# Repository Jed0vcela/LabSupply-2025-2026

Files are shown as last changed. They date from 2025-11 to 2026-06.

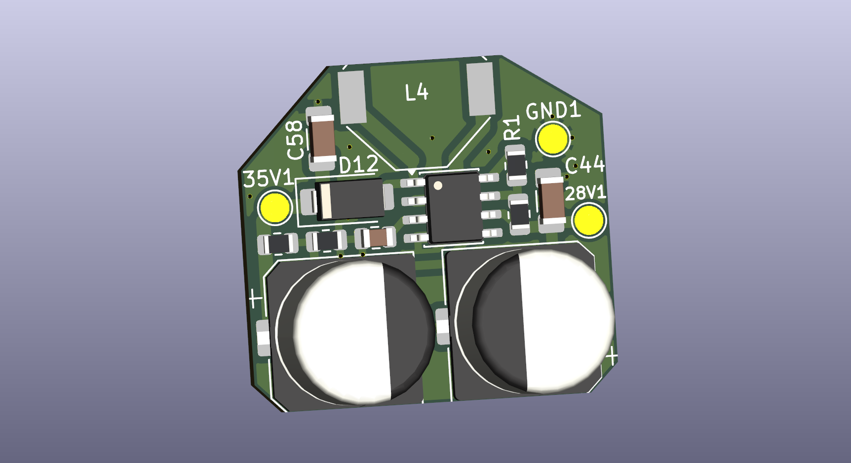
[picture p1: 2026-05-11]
KiCad soubory/OPamp_boost1/OPamp_boost1.png

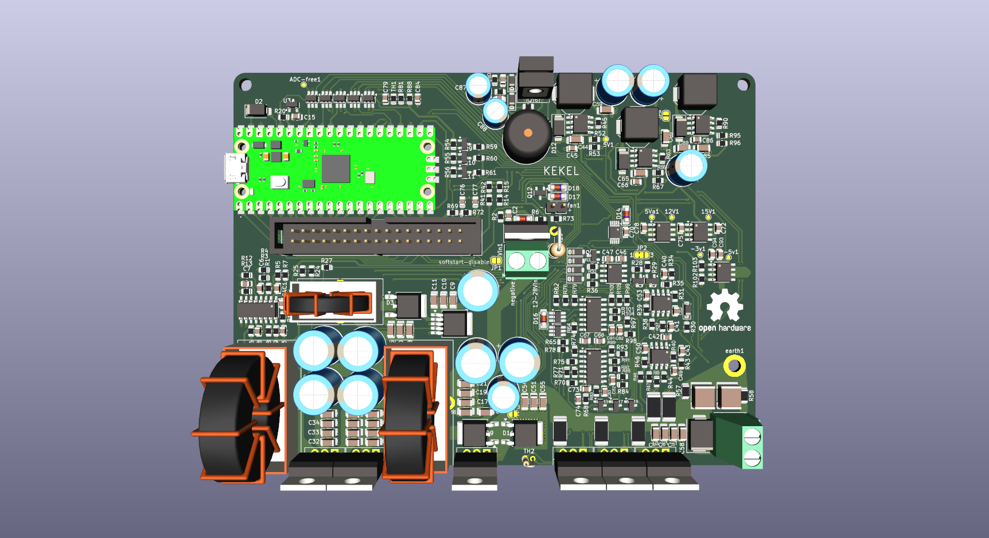
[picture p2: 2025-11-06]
KiCad soubory/Power board/LabSupply 2025-2026.png

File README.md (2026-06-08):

# Laboratorní napájecí zdroj + elektronická zátěž

Kombinovaný zdroj a elektronická zátěž na společných výstupních svorkách — vhodný pro nabíjení i vybíjení baterií.

## Napájení

- **USB-C** nebo **XT60** konektor (12–30 V, např. z akumulátorů)
- Výstupní napětí může být vyšší i nižší než vstupní (výstup **není galvanicky oddělen** od vstupu)

## Parametry

| Parametr | Hodnota |
|---|---|
| Výstupní napětí | 0 – 35 V |
| Výstupní proud (zdroj) | 0 – 4,5 A |
| Proudová zátěž | 0 – 3,8 A (max. 20 W) |

## Funkce

- **Zdroj** — nastavitelné napětí a proud (Vset, Iset)
- **Elektronická zátěž** — nastavitelný proudový sink (Isink), souběžně se zdrojem
- **Měřič kontinuity** — nastavitelný práh napětí, akustická signalizace
- **Ochrana výkonu** — konfigurovatelné limity Pout a Psink, ochrana při poklesu Vin
- **Kalibrace** — nastavení gain/offset pro každý měřený kanál, uložení do interní flash
- **Ukládání nastavení** — hodnoty Vset, Iset a Isink se ukládají do flash
- **IR dálkové ovládání** — NEC protokol, zatím není implementováno
- **LCD displej** — barevný 160×128 px, tři zobrazovací režimy

## Hardware

Raspberry Pi Pico (RP2040) · MCP4728 DAC · MCP23S17 · ST7735S LCD · rotační enkodér · NTC teplotní senzory · ventilátor · bzučák

## Dokumentace

Podrobný uživatelský manuál: [`manual_napajeci_zdroj.md`](manual_napajeci_zdroj.md)





LabSupply 2025-2026

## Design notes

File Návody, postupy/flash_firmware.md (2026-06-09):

# Nahrávání firmwaru

## Požadavky

- Micro USB kabel
- PC (Windows, macOS nebo Linux)
- Soubor `firmware.uf2` — stáhnout z [GitHub – Zkompilované programy](https://github.com/Jed0vcela/LabSupply-2025-2026/tree/main/Kompilovan%C3%A9%20programy)

---

## Postup nahrání firmwaru

**1.** Odpojte zdroj od napájení.

**2.** Odstraňte přední kryt zdroje.

**3.** Stiskněte a **držte** tlačítko **BOOTSEL** na Raspberry Pi Pico.

<!-- přidám obrázek -->
bootsel

**4.** Při stále stisknutém tlačítku připojte micro USB kabel do PC.  
Zdroj se zobrazí jako USB flash disk (mass storage) s názvem `RPI-RP2`.

**5.** Tlačítko BOOTSEL uvolněte.

**6.** Stáhněte nejnovější `firmware.uf2` z [GitHub – Zkompilované programy](https://github.com/Jed0vcela/LabSupply-2025-2026/tree/main/Kompilovan%C3%A9%20programy).

**7.** Přetáhněte soubor `firmware.uf2` na disk `RPI-RP2`.

<!-- přidám obrázek -->
nahrání fw

**8.** Zařízení se automaticky odpojí od PC, resetuje a spustí nový firmware.

---

## Vymazání paměti flash (reset kalibrace) (není normálně potřeba)

Hodnoty uložené v paměti FLASH (kalibrace, nastavení) **přežijí nahrání nového firmwaru**. Pokud jste v kalibračním menu uložili nesmyslné hodnoty a zdroj se chová nesprávně, je nutné paměť zcela vymazat.

> **Soubor ke stažení:** [`flash_nuke.uf2`](https://datasheets.raspberrypi.com/soft/flash_nuke.uf2) — oficiální nástroj od Raspberry Pi Foundation

### Postup

**1.** Odpojte zdroj od napájení.

**2.** Nahrajte `flash_nuke.uf2` stejným postupem jako firmware výše.  
   Zařízení se po nahrání samo resetuje — disk `RPI-RP2` zmizí.

**3.** Po pár sekundách se raspberry znova připojí.

**4.** Nahrajte "čistý" firmware dle postupu víše.

> Po vymazání flash se při prvním spuštění načtou **tovární výchozí hodnoty** kalibrace.

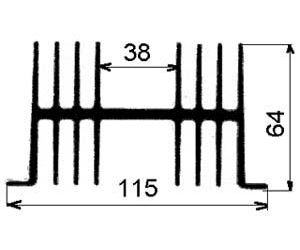
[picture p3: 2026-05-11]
3D files/o775c.jpg

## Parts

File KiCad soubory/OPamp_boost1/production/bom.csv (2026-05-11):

Designator | Footprint | Quantity | Value | LCSC Part #
28V1, 35V1, GND1 | TestPoint_Pad_D2.0mm | 3 | TestPoint_Probe
C1, C61 | CP_Elec_10x10 | 2 | 220u 50V
C44, C58 | 1206 | 2 | 1u
C45 | 0805 | 1 | 200p
D12 | D_SMA | 1 | D_Schottky
L4 | L_Bourns-SRU1028_10.0x10.0mm | 1 | 220u
R1 | 0805 | 1 | 180
R44 | 0805 | 1 | 1
R51 | 0805 | 1 | 27k
R52 | 0805 | 1 | 1k
U12 | SOIC-8_3.9x4.9mm_P1.27mm | 1 | MC34063AD

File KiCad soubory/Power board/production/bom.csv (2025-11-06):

Designator | Footprint | Quantity | Value | LCSC Part #
-3V1, -5V1, 12V1, 15V1, 5V1, 5VA1, ADC-FREE1 | TestPoint_Pad_D1.0mm | 7 | TestPoint_Probe
A1 | PICO | 1 | RaspberryPi_Pico
C1, C15, C3, C4, C46, C47, C49, C5, C50, C52, C53, C67, C68, C70, C72, C75, C78, C79, C84, C93 | 0805 | 20 | 100n
C10, C11, C16, C17, C18, C19, C20, C21, C22, C23, C24, C25, C26, C27, C28, C29, C30, C31, C32, C33, C34, C35, C9 | 1206 | 23 | 2u2
C12, C6, C8, C94 | 0805 | 4 | 1u
C13, C14, C36, C37, C38, C39, C48 | CP_Radial_D10.0mm_P5.00mm | 7 | 470u
C2, C80, C81 | 0805 | 3 | 4u7
C40, C42, C45, C73, C82, C86, C91 | 0805 | 7 | 100p
C41, C43, C74, C83, C92, R37, R43, R68, R83, R97 | 0805 | 10 | NC
C44, C51, C54, C55, C57, C58, C59, C60, C61, C65, C69, C85, C89 | 1206 | 13 | 1u
C56 | CP_Radial_D8.0mm_P5.00mm | 1 | 22u
C62, C71, C90 | CP_Radial_D8.0mm_P5.00mm | 3 | 220u
C63, C64 | 2220 | 2 | 10n
C66 | 0805 | 1 | 330p
C7 | 0805 | 1 | 1n
C76, C77 | 0805 | 2 | 10n
C87, C88 | CP_Radial_D6.3mm_P2.50mm | 2 | 100u
D1 | D_MiniMELF | 1 | 15V
D10, D19, D20, D5, D6, D7, D8 | D_SOD-123 | 7 | LL4148
D11, D3, D9 | TO-252-2 | 3 | D_Schottky_AKA
D12, D15, D2, D21 | D_SMA | 4 | D_Schottky
D13 | D_SMC | 1 | 1N62xxA
D14, D17 | D_MiniMELF | 2 | LL4148
D16 | D_MiniMELF | 1 | 2v4
D18 | D_MiniMELF | 1 | 3v9
D4 | TO-220-3_Vertical | 1 | D_Schottky_Dual_CommonCathode_AKA
FAN1 | PinHeader_1x02_P2.54mm_Vertical | 1 | Conn_01x02_Pin
J1 | IDC-Header_2x17_P2.54mm_Vertical | 1 | Conn_02x17_Odd_Even
L1 | L_Toroid_Vertical_L21.6mm_W11.4mm_P7.62mm_Pulse_KM-3 | 1 | HCTI-56-10.2
L2, L3 | L_Toroid_Vertical_L31.8mm_W15.9mm_P13.50mm_Bourns_5700 | 2 | HCTI-27-15.6
L4, L6 | L_Bourns-SRU1028_10.0x10.0mm | 2 | 220u
L5 | L_Bourns-SRU1028_10.0x10.0mm | 1 | 470u
LS1 | Buzzer_12x9.5RM7.6 | 1 | Speaker
Q1, Q14, Q18, Q20, Q4 | TO-220-3_Vertical | 5 | BUZ11
Q10, Q11, Q12, Q13, Q17, Q19, Q9 | SOT-23 | 7 | 2N7002K
Q15 | TO-126-3_Vertical | 1 | BD139
Q16 | TO-126-3_Vertical | 1 | BD136
Q2, Q6 | SOT-23 | 2 | BC817
Q3 | SOT-23-3 | 1 | BC808
Q5, Q7 | SOT-23 | 2 | BC807
Q8 | TO-220-3_Vertical | 1 | TIP41B
R1, R104, R105, R13, R27, R28, R31, R32, R33, R34, R36, R39, R40, R48, R49, R69, R70, R71, R72, R77, R78, R82, R84, R85, R92, R93, R98, R99 | 0805 | 28 | 2k2
R10 | R_Axial_DIN0411_L9.9mm_D3.6mm_P5.08mm_Vertical | 1 | 10
R100, R101, R14, R22, R35, R41, R6, R7, R74, R75, R79, R8, R89, R91 | 0805 | 14 | 47k
R102, R52, R95 | 0805 | 3 | 3k
R103, R20, R53, R67, R96 | 0805 | 5 | 1k
R106 | 2512 | 1 | 500m
R11, R12, R3, R5, R54, R55, R56, R59, R60, R61, R81, R88 | 0805 | 12 | 10k
R15, R4, R42 | 0805 | 3 | 4k7
R16, R25, R29, R30, R9 | 0805 | 5 | 1k2
R17, R19, R21, R73 | 0805 | 4 | 10
R18 | 0805 | 1 | 0
R2, R46 | 0805 | 2 | 1M
R23, R26 | 2512 | 2 | 10m
R24, R38, R76, R86, R87 | 0805 | 5 | 33k
R44, R47, R62, R64, R65 | 0805 | 5 | 39k
R45, R63, R90 | 0805 | 3 | 1
R50, R51, R80, R94 | 2512 | 4 | 50m
R57, R58 | 1206 | 2 | 1M
R66 | 0805 | 1 | 11k
TH1 | 0805 | 1 | Thermistor_NTC
TH2 | R_Axial_DIN0204_L3.6mm_D1.6mm_P1.90mm_Vertical | 1 | Thermistor_NTC
U1 | SOIC-16_3.9x9.9mm_P1.27mm | 1 | TL494
U10, U11, U9 | SOIC-8_3.9x4.9mm_P1.27mm | 3 | RC4580
U12, U15, U21 | SOIC-8_3.9x4.9mm_P1.27mm | 3 | MC34063AD
U13, U14, U4, U5, U6, U7, U8 | SOT-23-6_Handsoldering | 7 | 74LVC1G3157
U16, U18 | SOIC-14_3.9x8.7mm_P1.27mm | 2 | LM324
U17 | MSOP-10_3x3mm_P0.5mm | 1 | MCP4728
U19 | SOIC-8_3.9x4.9mm_P1.27mm | 1 | L78L12_SO8
U2 | TO-252-5_TabPin3 | 1 | APE1707H-HF
U20 | SOIC-8_3.9x4.9mm_P1.27mm | 1 | L78L05_SO8
U22 | SOIC-8_3.9x4.9mm_P1.27mm | 1 | LM337L_SO8
U3 | SOT-23 | 1 | LM4040DBZ-3
VIN1 | TerminalBlock_MetzConnect_Type055_RT01502HDWU_1x02_P5.00mm_Horizontal | 1 | Vin
VOUT1 | TerminalBlock_MetzConnect_Type055_RT01502HDWU_1x02_P5.00mm_Horizontal | 1 | Screw_Terminal_01x02

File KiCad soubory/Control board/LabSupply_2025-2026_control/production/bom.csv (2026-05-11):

Designator | Footprint | Quantity | Value | LCSC Part #
C1, C10, C11, C12, C13, C14, C15, C16, C2, C4, C5, C6, C7, C8, C9 | 0805 | 15 | 100n
C3 | 0805 | 1 | 1u
J1 | IDC-Header_2x17_P2.54mm_Vertical | 1 | Conn_02x17_Odd_Even
R1, R10, R11, R12, R13, R14, R15, R4, R5, R6, R7, R8, R9 | 0805 | 13 | 10k
R16, R17, R18, R19, R20, R21, R22, R23, R24 | 0805 | 9 | 1k
R2 | 0805 | 1 | 22k
R3 | 0805 | 1 | 47
SW1, SW2, SW3, SW4, SW5, SW6, SW7, SW8, SW9 | SW_Cherry_MX_1.00u_PCB_LED | 9 | SW_MEC_5G_LED
SW10 | RotaryEncoder_Alps_EC11E-Switch_Vertical_H20mm | 1 | RotaryEncoder
U1 | SOIC-28W_7.5x17.9mm_P1.27mm | 1 | MCP23S17_SO
U2 | Vishay_MOLD-3Pin | 1 | TSOP45xx
U3 | ST7735_1,8_128x160 | 1 | ST7735_1,8
U4 | SOIC-8_3.9x4.9mm_P1.27mm | 1 | M95160-WMN6P

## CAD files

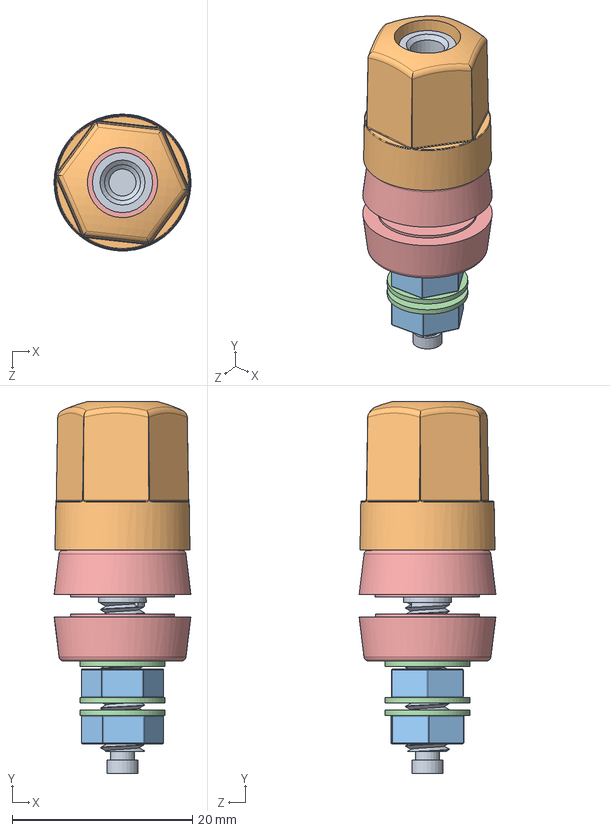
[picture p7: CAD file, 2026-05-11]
3D files/PwrBrd/single-banana-jack-1.snapshot.2/Banana Jack/Banana simple_rojo.SLDASM
15.2 x 41.3 x 15.2 mm
contact pin
Knob
moertje x 2
ring x 3
baseplate x 2

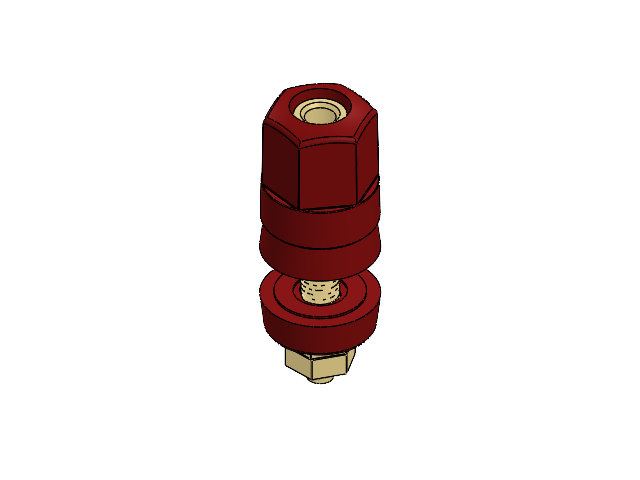
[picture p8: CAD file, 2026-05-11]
3D files/PwrBrd/single-banana-jack-1.snapshot.2/Banana simple_rojo.SLDASM
contact pin
Knob
moertje x 2
baseplate x 2

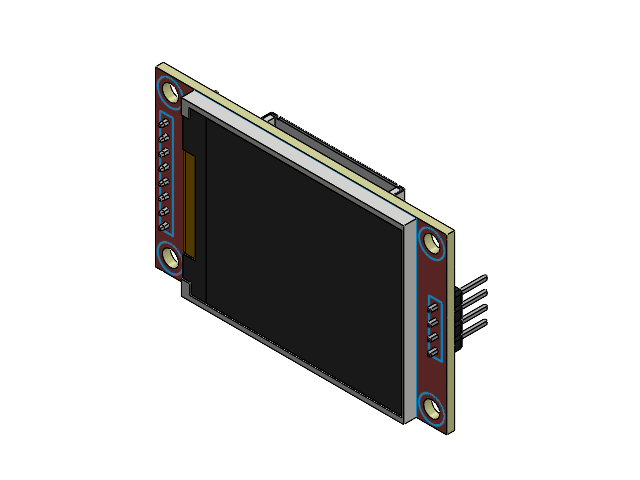
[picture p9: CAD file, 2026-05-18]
3D files/controlBrd/TFT LCD 1.8 inch ST7735.SLDASM
R0603~R0603~fHK2 x 4
SOT-23-3_L2.9-W1.3-P1.90-LS2.4-BR~SOT-23-3P_L2.9-W1.3-H1.0-LS2.4-P0.95~fHK2
HDR-TH_4P-P2.54-V-M~HDR-TH_4P-P2.54-M-LI-1X4P~fHK2
SD-CARD-SMD_SD-CARD-11P~SD-CARD-SMD_SD-CARD-11P~fHK2
C0603~C0603_L1.6-W0.8-H0.8~fHK2
HDR-TH_8P-P2.54-V-M~HDR-TH_8P-P2.54-V-M~fHK2
Board~fHK2
TopSilkscreen~fHK2
BottomSilkscreen~fHK2

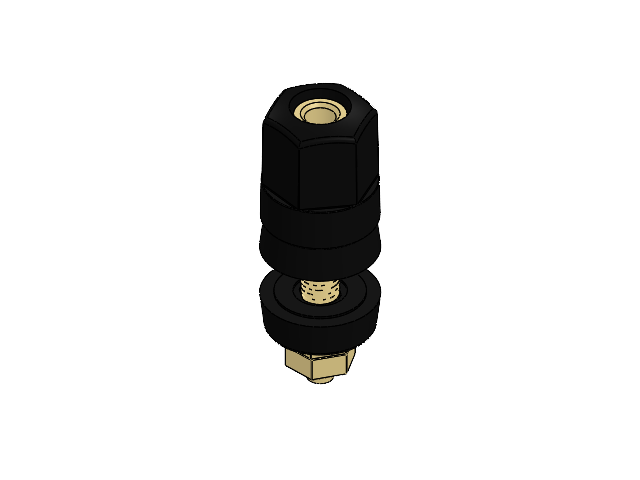
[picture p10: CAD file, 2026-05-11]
3D files/PwrBrd/single-banana-jack-1.snapshot.2/Banana Jack/Banana simple_negro.SLDASM
contact pin
Knob
moertje x 2
baseplate x 2

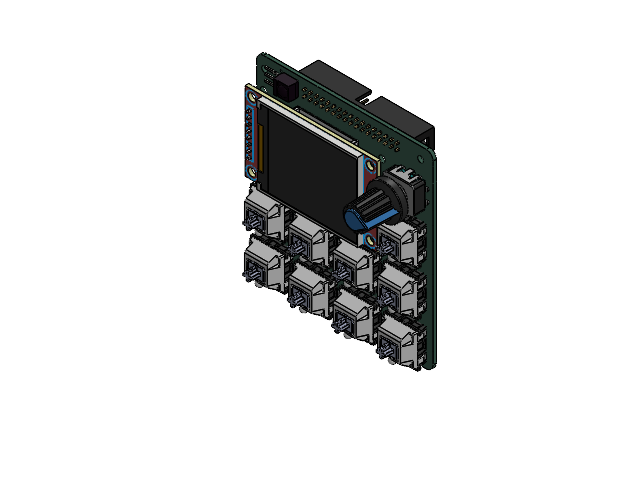
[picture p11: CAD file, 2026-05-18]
3D files/controlBrd/LabSupply_2025-2026_control.SLDASM
Bottom x 9
Pulsador x 9
Top x 9
Pieza5_Cherry MX x 9
Pin1 x 9
Pin2 x 9
Led 3mm_trans x 9
R0603~R0603~fHK2 x 4
SOT-23-3_L2.9-W1.3-P1.90-LS2.4-BR~SOT-23-3P_L2.9-W1.3-H1.0-LS2.4-P0.95~fHK2
HDR-TH_4P-P2.54-V-M~HDR-TH_4P-P2.54-M-LI-1X4P~fHK2
SD-CARD-SMD_SD-CARD-11P~SD-CARD-SMD_SD-CARD-11P~fHK2
C0603~C0603_L1.6-W0.8-H0.8~fHK2
HDR-TH_8P-P2.54-V-M~HDR-TH_8P-P2.54-V-M~fHK2
Board~fHK2
TopSilkscreen~fHK2
BottomSilkscreen~fHK2
Vishay_MOLD-3Pin
EC12E20-24P24C-SW
R_0805_2012Metric x 24
IDC-Header_2x17_P2.54mm_Vertical
C_0805_2012Metric x 16
SOIC-28W_7.5x17.9mm_P1.27mm
SOIC-8_3.9x4.9mm_P1.27mm
LabSupply_2025-2026_control_PCB

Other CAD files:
3D files/controlBrd/R2~R0603~R0603~fHK2.SLDASM
3D files/PwrBrd/single-banana-jack-1.snapshot.2/Banana Jack/Knob.sldasm
3D files/controlBrd/H2~HDR-TH_4P-P2.54-V-M~HDR-TH_4P-P2.54-M-LI-1X4P~fHK2.SLDASM
3D files/controlBrd/U1~SD-CARD-SMD_SD-CARD-11P~SD-CARD-SMD_SD-CARD-11P~fHK2.SLDASM
3D files/controlBrd/C1~C0603~C0603_L1.6-W0.8-H0.8~fHK2.SLDASM
3D files/controlBrd/H1~HDR-TH_8P-P2.54-V-M~HDR-TH_8P-P2.54-V-M~fHK2.SLDASM
3D files/PwrBrd/PICO.SLDASM
3D files/controlBrd/LabSupply_2025-2026_control 1.13.1.SLDASM
3D files/controlBrd/Q1~SOT-23-3_L2.9-W1.3-P1.90-LS2.4-BR~SOT-23-3P_L2.9-W1.3-H1.0-LS2.4-P0.95~fHK2.SLDASM
3D files/PwrBrd/single-banana-jack-1.snapshot.2/Banana Jack/Banana simple.SLDASM
3D files/Banana simple_negro.SLDASM
3D files/controlBrd/R3~R0603~R0603~fHK2.SLDASM
3D files/Banana simple_rojo.SLDASM
3D files/100W 24V power supply.SLDPRT
3D files/60mm fan.SLDPRT
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

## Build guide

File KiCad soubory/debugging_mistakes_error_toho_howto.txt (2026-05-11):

TL431 SEPIC converter
soft start
inverted gate drive logic

DAC
internal VREF and gain set to 2 (max 4.096V) to minimize zero offset - need to change feedback dividers to not increase output voltage too much to destroy HW
15k pulldown to -3v3 doesnt lower 10mV zero offset for some reason (should be about 2mV max from datasheet) (on voltage output - outC)

jumper JP2 solder to select gnd - short position 1 and 2. otherwise feedback loop wont work properly.
jumper JP1 solder if soft start on input isnt used.

Place fuse on output - for discharging and charging batteries essential.

For future version shottky diode supply ORing? and vsense for all supplies?

Boost converter for U10 opamp

there is low impedance path output of opamp istead of negative feedback on U9. lift pin 7 and short pin 5 and 6 together.

filtering after dc-dc converter stage?

filters on ADC inputs?

output BJT has too much voltage when oparating, fix.

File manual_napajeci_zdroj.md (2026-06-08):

# Laboratorní napájecí zdroj — Uživatelský manuál

---

## Obsah

1. [Přehled hardware](#1-přehled-hardware)
2. [Tlačítka a ovládací prvky](#2-tlačítka-a-ovládací-prvky)
3. [Displej a zobrazené hodnoty](#3-displej-a-zobrazené-hodnoty)
4. [Režimy provozu](#4-režimy-provozu)
5. [Ovládání výstupu](#5-ovládání-výstupu)
6. [Nastavení kroku enkodéru](#6-nastavení-kroku-enkodéru)
7. [Kalibrační menu](#7-kalibrační-menu)
8. [Ochrana a omezení výkonu](#8-ochrana-a-omezení-výkonu)
9. [IR dálkové ovládání](#9-ir-dálkové-ovládání)

---

## 1. Přehled hardware

| Komponenta | Popis |
|---|---|
| Raspberry Pi Pico (RP2040) | Hlavní řídicí jednotka |
| ST7735S 128×160 LCD | Barevný displej, landscape 160×128 px |
| MCP4728 DAC | 4kanálový D/A převodník, nastavení výstupů |
| MCP23S17 expandér | Vstupní tlačítka a indikační LED |
| Rotační enkodér | Nastavení hodnot, tlačítko = potvrzení |
| IR přijímač (GP1) | Ovládání dálkovým ovladačem |
| Ventilátor (GP22) | Chlazení, řízeno teplotou |
| Bzučák (GP14) | Akustická signalizace |

---

## 2. Tlačítka a ovládací prvky

### Rotační enkodér

| Akce | Funkce |
|---|---|
| Otočení | Změna vybrané hodnoty (dle kroku) |
| Stisk (GPA1) | Potvrzení / přepnutí sloupce v menu |

### Tlačítka na expandéru MCP23S17

| Tlačítko | Funkce |
|---|---|
| **GPA0** | Zapnutí/vypnutí výstupu Source (Vset + Iset) |
| **GPA1** | Tlačítko enkodéru — potvrzení v menu |
| **GPB0** | Výběr kanálu **Vset** |
| **GPB1** | Krok enkodéru ×100 (momentary) nebo reset na ×1 (toggle) |
| **GPB2** | Výběr kanálu **Iset** |
| **GPB3** | Krok enkodéru ×10 (momentary) nebo cyklus ×1→×10→×100 (toggle) |
| **GPB4** | Výběr kanálu **Isink** |
| **GPB5** | Vstup do kalibračního menu / Výstup z menu |
| **GPB6** | Zapnutí/vypnutí výstupu Sink (Isink) |
| **GPB7** | Přepnutí režimu zobrazení (Supply+Sink → Supply → Continuity) |

> **Poznámka:** Tlačítka jsou aktivní v logické nule (active-low). Interní pull-up rezistory jsou zapnuty.

---

## 3. Displej a zobrazené hodnoty

### Barevné kódování

| Barva | Význam |
|---|---|
| Bílá | Normální hodnota |
| Žlutá | Aktivně vybraný kanál (enkodér edituje tuto hodnotu) |
| Zelená | Výstup zapnut / měřená hodnota v normě |
| Červená | Výstup vypnut / chyba |
| Oranžová | Varování / aktivní omezení výkonu |
| Šedá | Výstup nebo kanál je deaktivován |
| Azurová | Záhlaví / informační zpráva |

### Indikátory ve spodní liště

| Zobrazení | Popis |
|---|---|
| `source ON` / `source OFF` | Stav výstupu zdroje (zelená/červená) |
| `sink ON` / `sink OFF` | Stav výstupu zátěže (zelená/červená) |
| `step x1` / `x10` / `x100` | Aktuální krok enkodéru |
| `backlight XX%` | Aktuální jas podsvícení |

### Zprávy a upozornění

V dolní části displeje se zobrazují překryvné zprávy:

| Zpráva | Barva | Popis |
|---|---|---|
| `WARN: Pout limit active` | Oranžová | Překročen maximální výstupní výkon |
| `WARN: Psink limit active` | Oranžová | Překročen maximální výkon Sinku |
| `ERR: Vin too low` | Červená | Příliš nízké vstupní napětí |
| `CONTINUITY: closed` | Oranžová | Detekováno propojení (Continuity) |
| `IR: cmd=0xXX` | Azurová | Přijat kód z IR dálkového ovladače (3 s) |

---

## 4. Režimy provozu

Režimy se přepínají tlačítkem **MODE** — každým stiskem se přejde na další:

```
Supply + Sink  →  Supply  →  Continuity  →  Supply + Sink  →  ...
```

### 4.1 Režim Supply + Sink (výchozí)

Plné zobrazení všech hodnot:

| Levý sloupec (setpointy) | Pravý sloupec (měření) |
|---|---|
| Vset — nastavené napětí | Vout — měřené výstupní napětí |
| Iset — nastavený proud | Iout — měřený výstupní proud |
| Isink — nastavení proudového sinku | Pout — vypočítaný výstupní výkon |
| Tcore — teplota jádra RP2040 | Psink — výkon proudové zátěže |
| Tfan — teplota chladiče  | Isink — měřený proud zátěže |
| | Vin — měřené vstupní napětí |

### 4.2 Režim Supply

Zjednodušené zobrazení pouze pro napájecí zdroj:
- Vout a Iout zobrazeny **velkým písmem** (měřítko ×3)
- Vset, Iset zobrazeny malým písmem nahoře
- Spodní řádek: Pout, Tfan, Vin
- **Isink je při vstupu do tohoto režimu automaticky vypnut**

V tomto režimu jsou přístupné kanály **Vset** a **Iset**.

### 4.3 Režim Continuity (měřič spojitosti)

Určen pro testování propojení (odpory, kabely, pájené spoje):

| Levý sloupec | Pravý sloupec |
|---|---|
| Vset — testovací napětí | Vout — měřené napětí |
| Iset — testovací proud | Iout — měřený proud |
| Thr — práh detekce | |

Pokud naměřené napětí **klesne pod nastavený práh**, zobrazí se `CLOSED` (červeně) a bzučák vydá nepřerušovaný tón. Po překročení prahu se zobrazí `OPEN` (zeleně) a bzučák ztichne.

> **Vset, Iset a práh Thr** v režimu Continuity jsou **oddělené** od hodnot v režimu Supply+Sink — navzájem se neovlivňují a ukládají se do paměti flash nezávisle.

Výběr editovaného parametru:

| Tlačítko | Kanál |
|---|---|
| Vout | Vset |
| Iout | Iset |
| Isink | Thr (práh) |

---

Super na testování součástek / jestli kabel není přerušený atd... Pro pořádný test je možné narozdíl od multimetru měřeným spojem prohnat i několik A. Možné použít i pro měření diod a tranzistorů.

## 5. Ovládání výstupu

### Zapnutí/vypnutí zdroje (napájení)

Tlačítkem **OUT** se přepíná stav výstupu zdroje:
- Zapnuto → `source ON` (zeleně), LED svítí
- Vypnuto → `source OFF` (červeně), LED nesvítí

### Zapnutí/vypnutí zátěže

Tlačítkem **SINK** se přepíná stav zátěže:
- Zapnuto → `sink ON` (zeleně), LED svítí
- Vypnuto → `sink OFF` (červeně), LED nesvítí

## 6. Nastavení kroku enkodéru

Krok enkodéru určuje, o kolik DAC bitů se změní hodnota při jednom „kliknutí".

### Režim Momentary (výchozí)

Krok platí po dobu, kdy je tlačítko fyzicky stisknuto:

| Stav tlačítek | Krok |
|---|---|
| Žádné | ×1 |
| GPB3 držen | ×10 |
| GPB1 držen | ×100 |
| GPB1 + GPB3 oba drženy | ×1000 |

### Režim Toggle

Každý stisk tlačítka přepne krok a ten zůstane aktivní i po uvolnění:

| Akce | Výsledek |
|---|---|
| Stisk GPB3 | Cyklus: ×1 → ×10 → ×100 → ×1 |
| Stisk GPB1 | Reset na ×1 |

Přepínání mezi režimy se provádí v **kalibračním menu** (položka `Step mode`).
V budouucnu asi bude změněno.

---

## 7. Kalibrační menu

### Vstup a výstup

- **MENU** — vstup do menu
- **MENU** znovu (uvolnit a znovu stisknout) — výstup **bez uložení**
- **tlačítko enkodéru** na položce `Exit` — výstup bez uložení
- **tlačítko enkodéru** na položce `Save+Exit` — uložení do paměti flash a výstup z menu

### Navigace

| Akce | Funkce |
|---|---|
| Otočení enkodéru (levý sloupec) | Pohyb po položkách menu |
| GPA1 | Přepnutí do pravého sloupce (editace hodnoty) |
| Otočení enkodéru (pravý sloupec) | Změna hodnoty |
| GPA1 (v pravém sloupci) | Potvrzení a návrat do levého sloupce |

Menu má tři sloupce:
- **Název** — popis parametru
- **Hodnota** — aktuální hodnota (žlutě při editaci, oranžově při aktivní změně)
- **Výchozí** — tovární hodnota (šedě, pouze pro přehled)

### Přehled položek menu

| Položka | Popis | Rozsah |
|---|---|---|
| Exit | Výstup bez uložení | — |
| Save+Exit | Uložení do flash a výstup | — |
| **Plim on** | Povolení omezení výkonu | on / off |
| **Pout max W** | Maximální výstupní výkon | 0–200 W |
| **Psink max W** | Maximální výkon sinku | 0–200 W |
| **Vin min V** | Minimální vstupní napětí (mV krok 100) | 0–60 000 mV |
| **Beep** | Režim bzučáku | ALL / ALARM / MUTE |
| **Backlight** | Jas podsvícení | 1–100 % |
| **Step mode** | Režim tlačítek kroku | moment / toggle |
| Vout gain | Zisk pro měření výstupního napětí | 1–99999 |
| Vout offset | Offset pro měření výstupního napětí (mV) | ±9999 |
| Vin gain | Zisk pro měření vstupního napětí | 1–99999 |
| Vin offset | Offset pro měření vstupního napětí (mV) | ±9999 |
| HiI gain | Zisk pro měření proudu sinku | 1–99999 |
| HiI offset | Offset pro měření proudu sinku (mA) | ±9999 |
| Iout gain | Zisk pro měření výstupního proudu | 1–99999 |
| Iout offset | Offset pro měření výstupního proudu (mA) | ±9999 |
| Vset gain | Zisk pro zobrazení nastavení napětí | 1–99999 |
| Vset offset | Offset pro zobrazení nastavení napětí (mV) | ±9999 |
| Iset gain | Zisk pro zobrazení nastavení proudu | 1–99999 |
| Iset offset | Offset pro zobrazení nastavení proudu (mA) | ±9999 |
| Isink gain | Zisk pro zobrazení nastavení sinku | 1–99999 |
| Isink offset | Offset pro zobrazení nastavení sinku (mA) | ±9999 |

### Nastavení bzučáku

| Hodnota | Popis |
|---|---|
| ALL | Pípnutí při každém stisku tlačítka + alarmové události |
| ALARM | Pouze alarmové události (omezení výkonu, continuity) |
| MUTE | Tichý provoz (bzučák zcela vypnut) |

### Kalibrace měření (Gain a Offset)

Měřená hodnota se počítá takto:

```
zobrazená_hodnota = (raw_mV × gain / divisor) − offset
```

**Postup kalibrace výstupního napětí (Vout):**

1. Přiložte kalibrovaný voltmetr na výstupní svorky.
2. Zapněte Source (GPA0), nastavte nenulové Vset.
3. Porovnejte zobrazení Vout na displeji s voltmetrem.
4. Vstupte do kalibračního menu (GPB5).
5. Upravte `Vout gain` a `Vout offset` dokud se hodnoty neshodují.
6. Stejný postup pro ostatní měřené veličiny (Vin, HiI, Iout).
7. Uložte: `Save+Exit`.

> **Tip:** Začněte vždy od výchozích hodnot (výchozí sloupec v menu). Nejprve nastavte `gain` aby bylo měřítko správné, poté `offset` pro korekci nulového bodu.

---

## 8. Ochrana a omezení výkonu

Funkce omezení výkonu musí být povolena (`Plim on = on`).

### Omezení výstupního výkonu (Pout)

Pokud `Vout × Iout > Pout max`, zdroj automaticky snižuje **Vset** o 1 DAC krok za každou iteraci hlavní smyčky, dokud výkon neklesne pod limit. Po poklesu pod limit se Vset obnoví přirozeně — enkodérem.

Zobrazení: hodnota Vset se zobrazí **oranžově**, zpráva `WARN: Pout limit active`.

### Omezení výkonu zátěže (Psink)

Stejný mechanismus pro `Vout × Isink > Psink max` — snižuje se **Isink**.

Zobrazení: Isink setpoint oranžově, zpráva `WARN: Psink limit active`.

### Minimální vstupní napětí (Vin min)

Pokud `Vin < Vin min` (a hodnota je nenulová), dochází k automatickému snižování Vset.

Zobrazení: červená zpráva `ERR: Vin too low - reducing Vset`.

> **Poznámka:** Omezení výkonu jsou gradientní (plynulé snižování) — výstup **není okamžitě vypnut**. Pokud je potřeba okamžité vypnutí, použijte tlačítko GPA0.

---

## 9. IR dálkové ovládání

Zdroj podporuje IR dálkový ovladač s protokolem NEC (běžné televizní ovladače).

Po přijetí signálu se na displeji zobrazí: `IR: cmd=0xXX` (azurově, 3 sekundy).

### Nastavení příkazů

Příkazy jsou definovány v souboru `peripherals.h` jako konstanty:

```c
#define IR_CMD_VI_TOGGLE   0xFF   /* zapnutí/vypnutí Source */
#define IR_CMD_IS_TOGGLE   0xFF   /* zapnutí/vypnutí Sink   */
#define IR_CMD_SEL_VSET    0xFF   /* výběr kanálu Vset      */
#define IR_CMD_SEL_ISET    0xFF   /* výběr kanálu Iset      */
#define IR_CMD_SEL_ISINK   0xFF   /* výběr kanálu Isink     */
#define IR_CMD_ENC_UP      0xFF   /* enkodér nahoru ×1      */
#define IR_CMD_ENC_DOWN    0xFF   /* enkodér dolů ×1        */
```

`0xFF` znamená deaktivovaný příkaz.

Zatím není implementováno řizení zdroje přes IR, zatím je to pouze test.
---

## Rychlá reference — nejčastější úkony

| Úkon | Postup |
|---|---|
| Nastavit výstupní napětí | Vout (vybrat Vset) → otočit enkodér |
| Nastavit výstupní proud | Iout (vybrat Iset) → otočit enkodér |
| Zapnout výstup | OUT |
| Zapnout zátěž | SINK |
| Změnit krok ×10 (momentary) | Držet **10X** + otáčet enkodérem |
| Změnit krok ×10 (toggle) | Stisknout **10X** jednou |
| Přepnout režim | MODE |
| Vstoupit do kalibrace | MENU |
| Uložit kalibraci | MENU → navigovat na `Save+Exit` → Tlačítko enkodéru |
| Opustit kalibraci bez uložení | MENU (znovu stisknout) |

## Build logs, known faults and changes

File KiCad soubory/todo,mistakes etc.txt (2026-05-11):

DAC needs 5V to use full scane on gain 2 (0.000-4.096V)
for DAC 5V supply, level shift is needed on I2C, 10K pull up is good up to 400khz
RS232 peripherial? protection needed
DCDC converter cap size and capacity
inductor select
capacitors for opamps supply
low noise supply for opamps and analog parts
buy USB-C negotiation boards?

!!opamps supply needed and high voltage opamps preffered

Rocker switch https://www.tme.eu/cz/details/r515kkft0fa/prepinace-rocker/light-country-co-ltd/
Fuse holders? https://www.hadex.cz/p/k732-pojistkove-pouzdro-pro-autopojistku-19x12mm-na-panel-2

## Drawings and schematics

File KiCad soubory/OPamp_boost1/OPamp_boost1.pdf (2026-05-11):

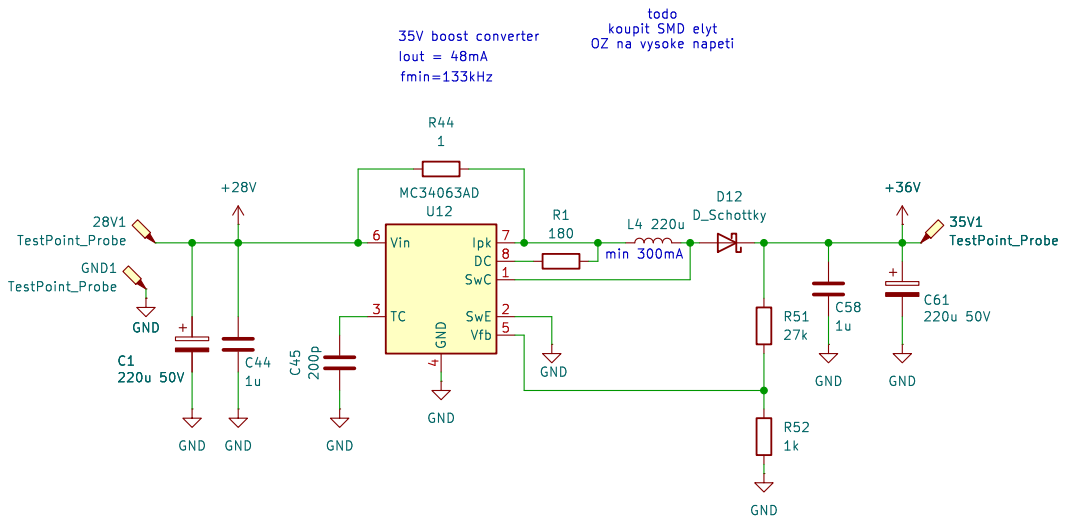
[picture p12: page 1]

koupit SMD elyt OZ na vysoke napeti Iout = 48mA

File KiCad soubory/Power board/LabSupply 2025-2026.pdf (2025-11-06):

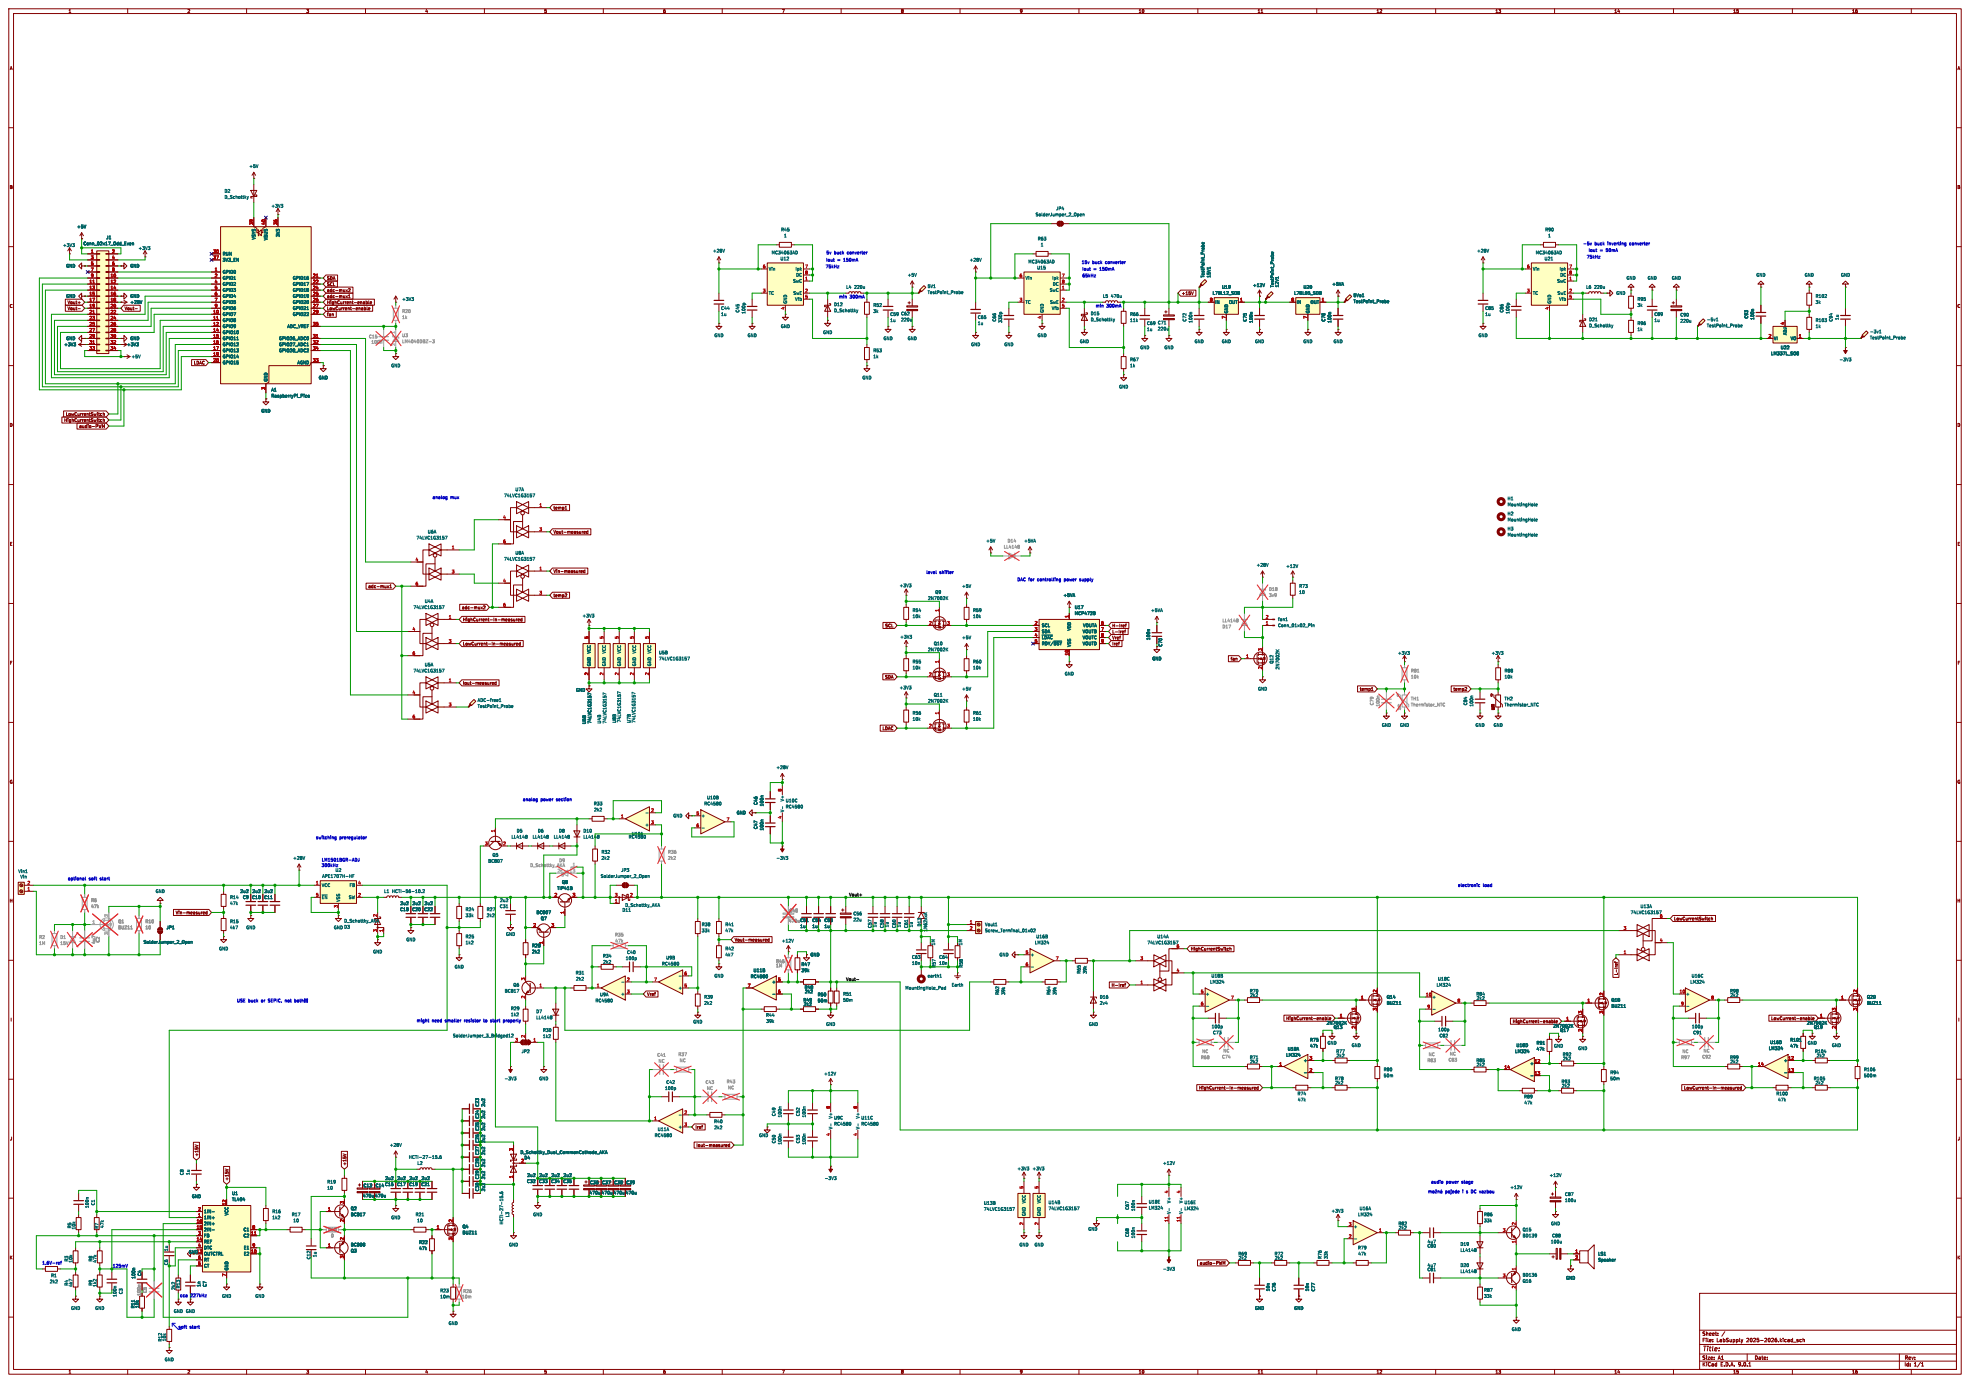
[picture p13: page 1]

Ipk 7 DC 8 SwC 1 SwE 2 Vfb 5 U12 MC34063AD

LowCurrent-enable HighCurrent-enable

3 2 Q12 2N7002K GND GND GND GND

3 FB 4 SW 2 U2 APE1707H-HF GND GND

þÿmo~ná pojede i s DC vazbou

Id: 1/1 Title: File: LabSupply 2025-2026.kicad_sch Sheet: /

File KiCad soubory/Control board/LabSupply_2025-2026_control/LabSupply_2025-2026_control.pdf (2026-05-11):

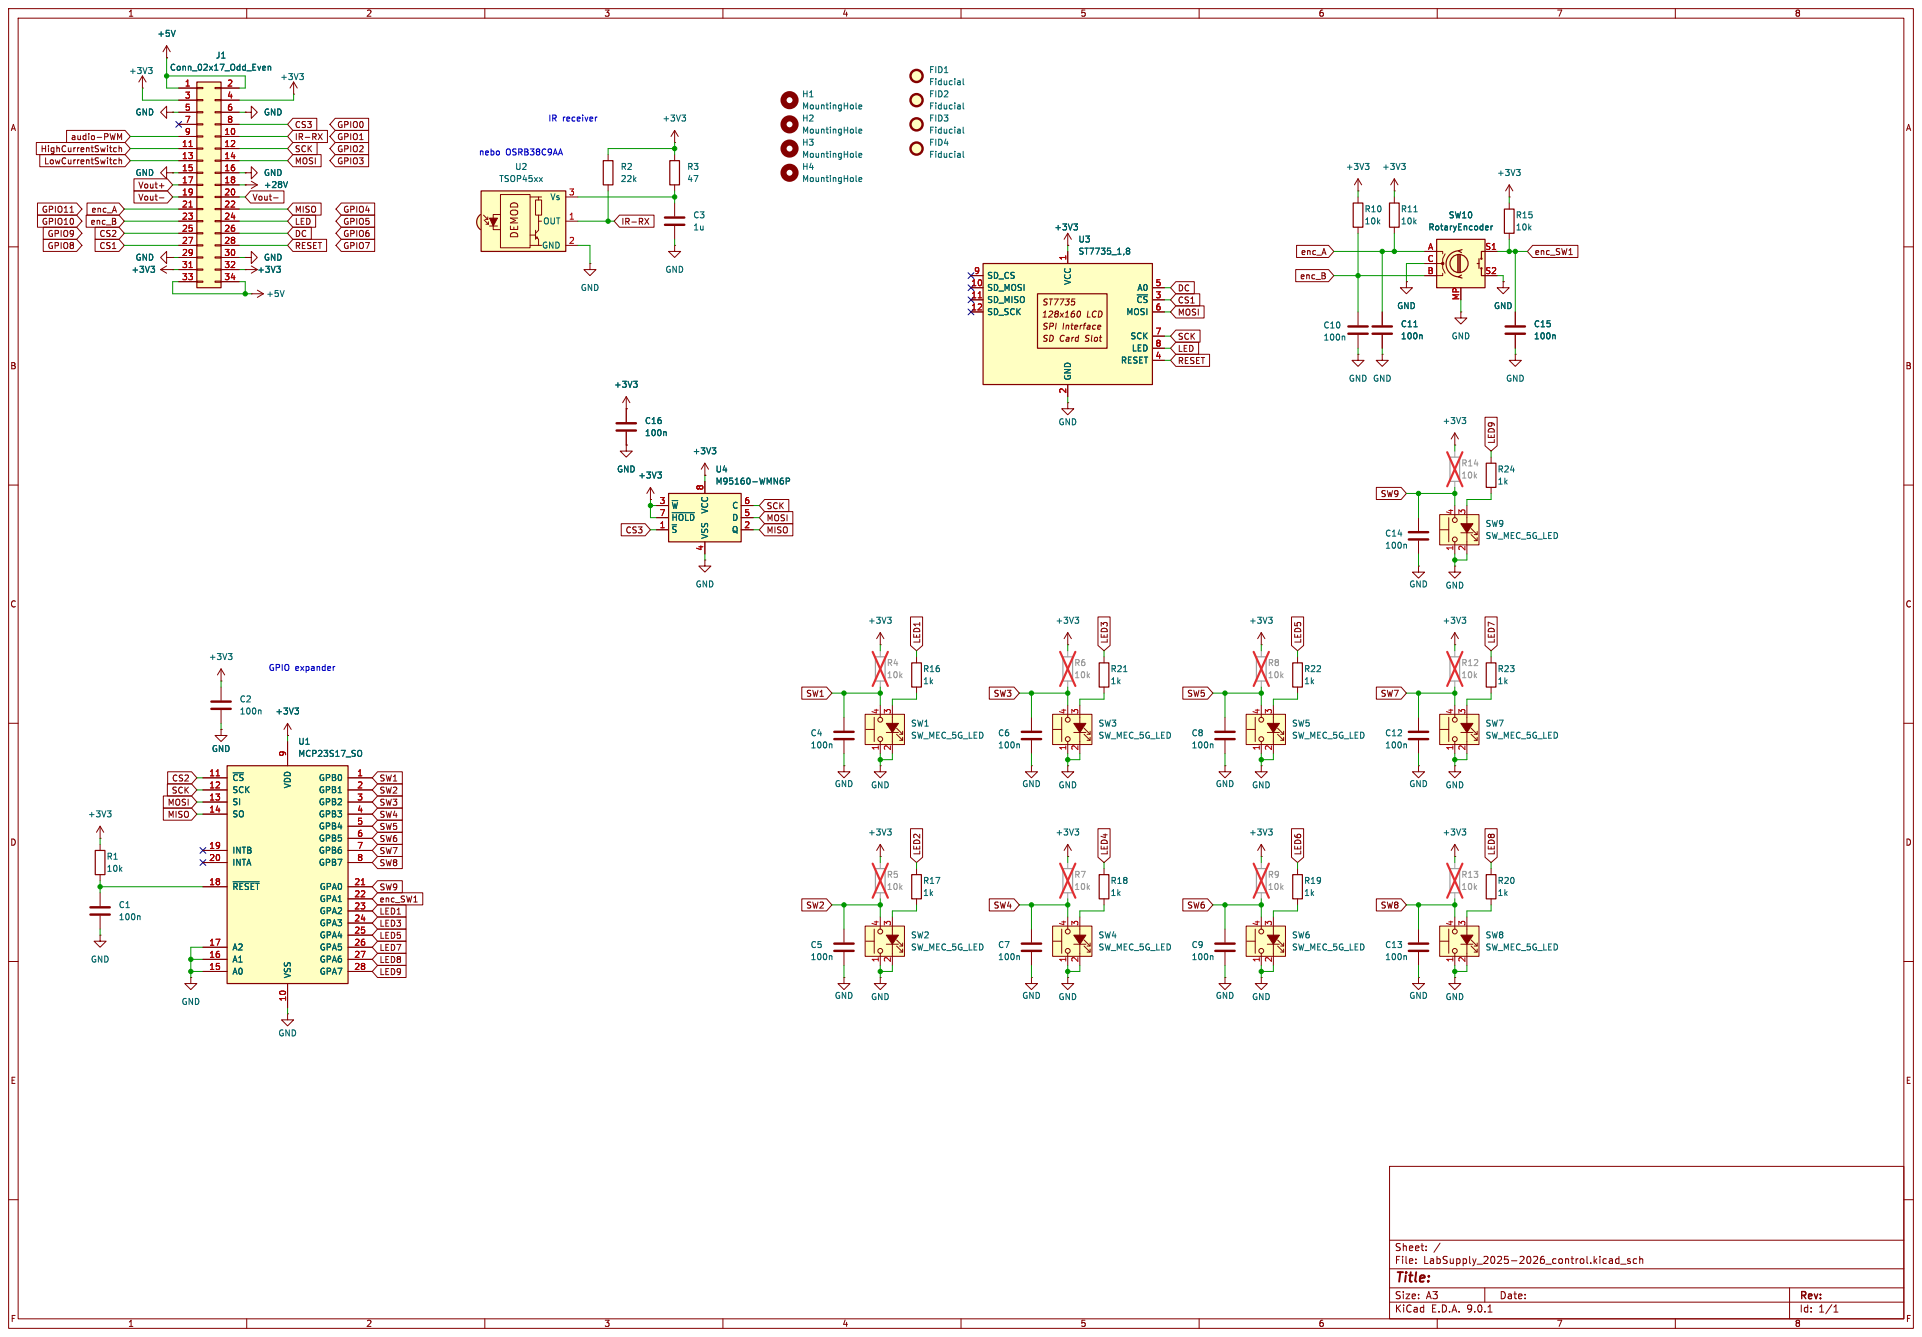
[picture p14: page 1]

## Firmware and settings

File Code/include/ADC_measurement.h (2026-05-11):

/**
 * adc_measurement.h
 * 
 * ADC voltage measurement with multiplexer support for RP2040
 * Uses 2 multiplexer control pins to select between 8 analog channels
 * 
 * Integer-only calibration system:
 * - All values in mV, mA, or mC (milli-units)
 * - No floating point math
 * - Per-channel gain and offset calibration
 */

#ifndef ADC_MEASUREMENT_H
#define ADC_MEASUREMENT_H

#include <stdint.h>
#include <stdbool.h>

#ifdef __cplusplus
extern "C" {
#endif

// Multiplexer control pins
#define ADC_MUX1_PIN         19
#define ADC_MUX2_PIN         18

// ADC hardware inputs (RP2040)
#define ADC_INPUT_0          0   // GPIO26
#define ADC_INPUT_1          1   // GPIO27
#define ADC_INPUT_2          2   // GPIO28

// ADC configuration
#define ADC_VREF_MV          3300     // Reference voltage in mV
#define ADC_RESOLUTION       4096     // 12-bit ADC (0-4095)
#define ADC_SETTLING_NOPS    2        // NOP delay for multiplexer settling

// ============================================================================
// DEFAULT CALIBRATION VALUES - CUSTOMIZE FOR YOUR HARDWARE
// ============================================================================
// These are the initial values loaded at startup
// You can modify these for your specific hardware, then each product can
// be fine-tuned individually after production if needed
//
// Formula: calibrated = ((raw_mv * gain) / divisor) - offset

#define DEFAULT_TEMP2_GAIN        100
#define DEFAULT_TEMP2_DIVISOR     1
#define DEFAULT_TEMP2_OFFSET      0

#define DEFAULT_LOW_CURRENT_GAIN      10
#define DEFAULT_LOW_CURRENT_DIVISOR   1
#define DEFAULT_LOW_CURRENT_OFFSET    50

#define DEFAULT_FREE_GAIN         1000
#define DEFAULT_FREE_DIVISOR      1000
#define DEFAULT_FREE_OFFSET       0

// Channel 3: VIN - Default for 10:1 voltage divider
#define DEFAULT_VIN_GAIN          18901
#define DEFAULT_VIN_DIVISOR       1703  
#define DEFAULT_VIN_OFFSET        250

#define DEFAULT_TEMP1_GAIN        100
#define DEFAULT_TEMP1_DIVISOR     1
#define DEFAULT_TEMP1_OFFSET      0

#define DEFAULT_VOUT_GAIN         11088
#define DEFAULT_VOUT_DIVISOR      1000
#define DEFAULT_VOUT_OFFSET       175

#define DEFAULT_HIGH_CURRENT_GAIN      16600
#define DEFAULT_HIGH_CURRENT_DIVISOR   1000
#define DEFAULT_HIGH_CURRENT_OFFSET    2500

#define DEFAULT_IOUT_GAIN         5405
#define DEFAULT_IOUT_DIVISOR      1000
#define DEFAULT_IOUT_OFFSET       50

// Generic defaults (used only if channel-specific defaults not defined)
#define DEFAULT_GAIN         1000     // Gain multiplier (1000 = 1.000x)
#define DEFAULT_DIVISOR      1000     // Divisor for gain (allows decimal precision)
#define DEFAULT_OFFSET       0        // DC offset to subtract (in mV/mA/mC)

int32_t adc_get_temp1_mC(void);
int32_t adc_get_temp2_mC(void);

int32_t adc_get_core_temp_mC(void);

// Channel indices in the readings structure
typedef enum {
    CHANNEL_TEMP2 = 0,
    CHANNEL_LOW_CURRENT_IN,
    CHANNEL_FREE,
    CHANNEL_VIN,
    CHANNEL_TEMP1,
    CHANNEL_VOUT,
    CHANNEL_HIGH_CURRENT_IN,
    CHANNEL_IOUT,
    ADC_NUM_CHANNELS
} adc_channel_t;

/**
 * Calibration parameters for a single channel
 * Formula: calibrated_value = ((raw_mv * gain) / divisor) - offset
 * 
 * Example: For a 10:1 voltage divider reading 12V as 1.2V
 *   gain = 10000, divisor = 1000, offset = 0
 *   Result: ((1200 * 10000) / 1000) - 0 = 12000 mV
 * 
 * Example: Current sensor with 100mV/A, 2.5V offset
 *   gain = 1000, divisor = 100, offset = 2500
 *   At 1A: ((2600 * 1000) / 100) - 2500 = 23500 mV = 1000 mA
 */
typedef struct {
    int32_t gain;       // Multiplier (e.g., 1000 = 1.000x, 2500 = 2.5x)
    int32_t divisor;    // Divisor (typically 1000 for 3 decimal places)
    int32_t offset;     // DC offset to subtract (in mV/mA/mC)
} adc_calibration_t;

/**
 * All calibration data for all channels
 * This struct can be stored in flash or EEPROM for persistence
 */
typedef struct {
    adc_calibration_t channels[ADC_NUM_CHANNELS];
    uint32_t magic;     // Magic number to verify valid calibration data
    uint32_t checksum;  // Simple checksum for data integrity
} adc_calibration_data_t;

#define CALIBRATION_MAGIC 0xCAFEBABE  // Magic number for valid calibration

/**
 * Structure to hold voltage measurements from all ADC channels
 */
typedef struct {
    uint16_t raw_values[ADC_NUM_CHANNELS];      // Raw ADC values (0-4095)
    int32_t  raw_mv[ADC_NUM_CHANNELS];          // Raw values in mV (before calibration)
    int32_t  calibrated[ADC_NUM_CHANNELS];      // Calibrated values (mV/mA/mC)
    uint32_t timestamp_ms;                      // Timestamp of measurement
    bool     valid;                             // True if measurement is valid
} adc_readings_t;

/**
 * Initialize ADC subsystem and multiplexer control pins
 * Loads default calibration values
 */
void adc_measurement_init(void);

/**
 * Read all 8 ADC channels through multiplexer
 * Reads raw values, converts to mV, and applies calibration
 * 
 * @param readings Pointer to struct where results will be stored
 * @return true if successful, false on error
 */
bool adc_read_all_channels(adc_readings_t *readings);

/**
 * Read all channels (raw values only, no conversion or calibration)
 * Fastest version - only reads ADC hardware
 * 
 * @param readings Pointer to struct where raw values will be stored
 * @return true if successful, false on error
 */
bool adc_read_all_raw(adc_readings_t *readings);

/**
 * Read a single channel (raw ADC value)
 * 
 * @param channel Channel to read (use adc_channel_t enum)
 * @return Raw ADC value (0-4095)
 */
uint16_t adc_read_channel_raw(adc_channel_t channel);

/**
 * Read a single channel and return calibrated value
 * 
 * @param channel Channel to read (use adc_channel_t enum)
 * @return Calibrated value in mV/mA/mC
 */
int32_t adc_read_channel_calibrated(adc_channel_t channel);

/**
 * Convert raw ADC value to millivolts (integer only)
 * Formula: mv = (raw * VREF_MV) / ADC_RESOLUTION
 * 
 * @param raw_value Raw ADC reading (0-4095)
 * @return Voltage in millivolts
 */
int32_t adc_raw_to_mv(uint16_t raw_value);

/**
 * Apply calibration to a raw mV value
 * Formula: calibrated = ((raw_mv * gain) / divisor) - offset
 * 
 * @param raw_mv Raw millivolt value
 * @param cal Pointer to calibration parameters
 * @return Calibrated value in mV/mA/mC
 */
int32_t adc_apply_calibration(int32_t raw_mv, const adc_calibration_t *cal);

/**
 * Convert all raw values to mV and apply calibration
 * 
 * @param readings Pointer to readings struct (raw_values must be populated)
 */
void adc_convert_and_calibrate(adc_readings_t *readings);

/**
 * Set calibration for a specific channel
 * 
 * @param channel Channel to calibrate
 * @param gain Gain multiplier (e.g., 1000 = 1.000x)
 * @param divisor Divisor (typically 1000)
 * @param offset DC offset in mV/mA/mC to subtract
 */
void adc_set_calibration(adc_channel_t channel, int32_t gain, int32_t divisor, int32_t offset);

/**
 * Get current calibration for a channel
 * 
 * @param channel Channel index
 * @param cal Pointer to calibration struct to fill
 */
void adc_get_calibration(adc_channel_t channel, adc_calibration_t *cal);

/**
 * Reset calibration for a channel to defaults
 * 
 * @param channel Channel to reset
 */
void adc_reset_calibration(adc_channel_t channel);

/**
 * Reset all channels to default calibration
 */
void adc_reset_all_calibration(void);

/**
 * Get pointer to current calibration data (for reading/saving)
 * 
 * @return Pointer to calibration data structure
 */
const adc_calibration_data_t* adc_get_calibration_data(void);

/**
 * Load calibration data (e.g., from flash/EEPROM)
 * Validates magic number and checksum
 * 
 * @param cal_data Pointer to calibration data to load
 * @return true if data is valid and loaded, false otherwise
 */
bool adc_load_calibration_data(const adc_calibration_data_t *cal_data);

/**
 * Calculate checksum for calibration data
 * 
 * @param cal_data Pointer to calibration data
 * @return Calculated checksum
 */
uint32_t adc_calculate_checksum(const adc_calibration_data_t *cal_data);

/**
 * Print ADC readings to console (for debugging)
 * 
 * @param readings Pointer to readings struct
 */
void adc_print_readings(const adc_readings_t *readings);

/**
 * Print calibration data for a channel
 * 
 * @param channel Channel to print
 */
void adc_print_calibration(adc_channel_t channel);

/**
 * Print all calibration data
 */
void adc_print_all_calibration(void);

/**
 * Get channel name as string (for debugging/display)
 * 
 * @param channel Channel index
 * @return Channel name string
 */
const char* adc_get_channel_name(adc_channel_t channel);

#ifdef __cplusplus
}
#endif

#endif // ADC_MEASUREMENT_H

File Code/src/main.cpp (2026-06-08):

/**
 * main.cpp  –  Lab power supply controller  v3
 *
 * ── Mode overview ───────────────────────────────────────────────────────
 *  MODE_SUPPLY_SINK  Full display: supply + current sink
 *  MODE_SUPPLY       Supply only, large Vout/Iout readout
 *  MODE_CONTINUITY   Continuity/resistance checker with threshold beep
 *
 *  GPB7 cycles through modes on every falling edge.
 *
 * ── File map ────────────────────────────────────────────────────────────
 *  psu_types.h       Shared types, constants, colours, geometry
 *  flash_store.h/.cpp  Flash persistence (cal_flash_t, g_cal)
 *  peripherals.h/.cpp  Encoder, IR, fan, beeper, backlight
 *  psu_control.h/.cpp  DAC, power limiting, button handling
 *  display.h/.cpp      All mode display functions + IR overlay
 *  cal_menu.h/.cpp     Calibration menu (blocking, 3-column)
 *  main.cpp            Mode state machine + main loop  ← this file
 */

#include "psu_types.h"
#include "flash_store.h"
#include "peripherals.h"
#include "psu_control.h"
#include "display.h"
#include "cal_menu.h"
#include "mcp4728.h"
#include "adc_measurement.h"
#include "mcp23s17.h"
#include "st7735.h"
#include <stdio.h>
#include "pico/stdlib.h"
#include "hardware/gpio.h"

/* ── Mode state ───────────────────────────────────────────────────────── */
static psu_mode_t g_mode = MODE_SUPPLY_SINK;

/* Called whenever the mode changes to set up the static screen and
 * adjust hardware state (e.g. disable Isink in supply-only mode). */
static void mode_enter(psu_mode_t m)
{
    g_mode = m;
    switch (m) {
    case MODE_SUPPLY_SINK:
        draw_supply_sink_static();
        break;
    case MODE_SUPPLY:
        g_isink_enabled = false;      /* auto-disable Isink in supply-only mode */
        g_active_ch     = DAC_VIRT_VSET;   /* always start on Vset */
        draw_supply_static();
        break;
    case MODE_CONTINUITY:
        g_isink_enabled = false;
        draw_continuity_static();
        break;
    default:
        break;
    }
}

/* Redraw current mode's static screen (passed to cal_menu_run as callback) */
static void mode_redraw_static(void)
{
    mode_enter(g_mode);
}

/* ── Moving average instances ─────────────────────────────────────────── */
static mav_t mav_vout, mav_iout, mav_hii, mav_tfan, mav_vin, mav_tcore;

static void mav_init_all(void)
{
    mav_init(&mav_vout,  0);  mav_init(&mav_iout, 0);  mav_init(&mav_hii,   0);
    mav_init(&mav_tfan,  25000); mav_init(&mav_vin, 0); mav_init(&mav_tcore, 25000);
}

/* ── Continuity encoder apply ─────────────────────────────────────────── */
static void apply_encoder_continuity(int32_t multiplier)
{
    int32_t delta = enc_consume();
    if (delta == 0) return;
    int32_t step = (int32_t)ENC_STEP * multiplier;

    int32_t *ptr = NULL;
    switch (g_cont_active) {
    case CONT_VSET: ptr = &g_cont_dac[0]; break;
    case CONT_ISET: ptr = &g_cont_dac[1]; break;
    case CONT_THR:  ptr = &g_cont_thr;    break;
    }
    if (!ptr) return;
    int32_t cnt = *ptr + delta * step;
    if (cnt < DAC_MIN_CNT) cnt = DAC_MIN_CNT;
    if (cnt > DAC_MAX_CNT) cnt = DAC_MAX_CNT;
    *ptr = cnt;
}

/* ── Continuity DAC update ────────────────────────────────────────────── */
static inline uint16_t ctr(int32_t v)
{
    if (v <= 0) return 0u;
    if (v >= DAC_MAX_CNT) return (uint16_t)DAC_MAX_COUNT;
    return (uint16_t)v;
}

static void dac_update_continuity(mcp4728 &dac)
{
    bool c_on = g_vi_enabled && (g_cont_dac[0] != 0);
    bool d_on = g_vi_enabled && (g_cont_dac[1] != 0);
    dac.setPowerDown(1, 1, c_on?0:1, d_on?0:1);
    dac.analogWriteAll(0, 0,
        c_on ? ctr(g_cont_dac[0]) : 0,
        d_on ? ctr(g_cont_dac[1]) : 0);
    dac.ldacPulse();
    gpio_put(PIN_EN_HI, 1); gpio_put(PIN_EN_LO, 1);
    mcp23s17_set_pin(MCP_OUT_GPA7, g_vi_enabled);
    mcp23s17_set_pin(MCP_OUT_GPA5, false);
}

/* ── Continuity button handling ───────────────────────────────────────── */
static void process_buttons_continuity(uint8_t gpa, uint8_t gpb)
{
    static uint8_t gpa_prev = 0xFFu, gpb_prev = 0xFFu;
    static bool primed = false;
    if (!primed) { gpa_prev = gpa; gpb_prev = gpb; primed = true; return; }

    uint8_t gpa_fell = (uint8_t)(gpa_prev & ~gpa);
    uint8_t gpb_fell = (uint8_t)(gpb_prev & ~gpb);
    if (gpa_fell || gpb_fell) beep();

    /* GPA0: toggle VI enable */
    if (gpa_fell & (1u<<0)) g_vi_enabled = !g_vi_enabled;

    /* GPB0/2/4: cycle continuity channel (Vset/Iset/Threshold) */
    if (gpb_fell & (1u<<0)) g_cont_active = CONT_VSET;
    if (gpb_fell & (1u<<2)) g_cont_active = CONT_ISET;
    if (gpb_fell & (1u<<4)) g_cont_active = CONT_THR;

    gpa_prev = gpa; gpb_prev = gpb;
}

/* ── Main ─────────────────────────────────────────────────────────────── */
int main(void)
{
    stdio_init_all();
    const uint led = 25;
    gpio_init(led); gpio_set_dir(led, GPIO_OUT);

    flash_load();

    mcp4728 dac(0x00);
    dac.begin();
    dac.setVref(1,1,1,1);
    dac.setGain(0,0,0,0);
    dac.setPowerDown(1,1,1,1);
    dac.analogWriteAll(0,0,0,0);
    dac.ldacPulse();

    hw_gpio_init();
    adc_measurement_init();
    cal_apply();

    /* Restore setpoints; outputs start DISABLED */
    for (uint8_t i = 0; i < DAC_NUM_CH; i++) g_dac_cnt[i] = g_cal.dac_cnt[i];
    g_cont_dac[0] = g_cal.cont.vset_cnt;
    g_cont_dac[1] = g_cal.cont.iset_cnt;
    g_cont_thr    = g_cal.cont.thr_cnt;
    g_vi_enabled = g_isink_enabled = false;

    mav_init_all();
    encoder_init();
    ir_init();
    fan_init();
    beeper_init();

    st7735_init();
    st7735_set_rotation(3);
    backlight_set(g_cal.backlight);

    mcp23s17_init();
    mode_enter(MODE_SUPPLY_SINK);

    uint64_t last_display_us = 0;

    while (true) {
        gpio_put(led, true); sleep_ms(1); gpio_put(led, false);

        /* ── IR decode ──────────────────────────────────────────────── */
        if (ir_decode() && g_ir_new) {
            g_ir_new = false;
            g_ir_show_until = time_us_64() + IR_DISPLAY_US;
            if (!g_ir_repeat) {
                uint8_t cmd = (uint8_t)((g_ir_code >> 16) & 0xFF);
                /* IR dispatch: expand as needed */
                if (cmd == IR_CMD_VI_TOGGLE)  g_vi_enabled    = !g_vi_enabled;
                if (cmd == IR_CMD_IS_TOGGLE)  g_isink_enabled = !g_isink_enabled;
            }
        }

        /* ── Buttons ────────────────────────────────────────────────── */
        uint8_t gpa_in, gpb_in;
        mcp23s17_read_inputs(&gpa_in, &gpb_in);

        bool gpb7_fell = false;
        bool enter_cal = false;

        if (g_mode == MODE_CONTINUITY) {
            process_buttons_continuity(gpa_in, gpb_in);
            /* GPB5 and GPB7 handled here with proper priming */
            static uint8_t gpb_prev_c = 0xFFu;
            static bool    gpb_c_primed = false;
            if (!gpb_c_primed) { gpb_prev_c = gpb_in; gpb_c_primed = true; }
            uint8_t gpb_fell_c = (uint8_t)(gpb_prev_c & ~gpb_in);
            gpb_prev_c = gpb_in;
            enter_cal = (bool)(gpb_fell_c & (1u<<5));
            gpb7_fell  = (bool)(gpb_fell_c & (1u<<7));
        } else {
            enter_cal = process_buttons_main(gpa_in, gpb_in, &gpb7_fell);
        }

        /* GPB7: cycle mode */
        if (gpb7_fell) {
            psu_mode_t next = (psu_mode_t)((g_mode + 1) % MODE_COUNT);
            mode_enter(next);
            process_buttons_main_reset();
            last_display_us = 0;
            continue;
        }

        /* GPB5: enter cal menu */
        if (enter_cal) {
            cal_menu_run(mode_redraw_static);
            process_buttons_main_reset();
            backlight_set(g_cal.backlight);
            last_display_us = 0;
            continue;
        }

        /* ── Encoder + DAC ──────────────────────────────────────────── */
        int32_t mult = encoder_step_multiplier(gpb_in);

        if (g_mode == MODE_CONTINUITY) {
            apply_encoder_continuity(mult);
            dac_update_continuity(dac);
        } else {
            apply_encoder_main(mult);
            dac_update(dac);
        }

        /* ── ADC + filter ───────────────────────────────────────────── */
        adc_readings_t r;
        if (!adc_read_all_channels(&r)) printf("ADC err\n");

        adc_bundle_t adc;
        adc.vout_mV  = mav_update(&mav_vout,  r.calibrated[CHANNEL_VOUT]);
        adc.iout_mA  = mav_update(&mav_iout,  r.calibrated[CHANNEL_IOUT]);
        adc.hii_mA   = mav_update(&mav_hii,   r.calibrated[CHANNEL_HIGH_CURRENT_IN]);
        adc.tfan_mC  = mav_update(&mav_tfan,  adc_get_temp2_mC());
        adc.vin_mV   = mav_update(&mav_vin,   r.calibrated[CHANNEL_VIN]);
        adc.tcore_mC = mav_update(&mav_tcore, adc_get_core_temp_mC());
        /* Power: Pout uses raw Iout; Psink uses HiI (Isink) directly */
        adc.pout_mW  = (adc.vout_mV * adc.iout_mA) / 1000;
        adc.psink_mW = (adc.vout_mV * adc.hii_mA)  / 1000;

        /* ── Fan ────────────────────────────────────────────────────── */
        fan_update(adc.tfan_mC);

        if (g_mode != MODE_CONTINUITY) {
            power_limit_update(adc.vout_mV, adc.iout_mA, adc.hii_mA);

            /* Vin minimum check */
            if (g_cal.plim_enabled && g_cal.vin_min_mV > 0 &&
                adc.vin_mV < g_cal.vin_min_mV && g_vi_enabled &&
                g_dac_cnt[DAC_CH_C] > 0) {
                g_dac_cnt[DAC_CH_C]--;
                msg_post(MSG_ERROR, "ERR: Vin too low - reducing Vset", 0u);
                if (!g_pout_limiting) beep_special();
                g_pout_limiting = true;
            } else if (g_cal.vin_min_mV > 0 && adc.vin_mV >= g_cal.vin_min_mV
                       && g_pout_limiting && !g_psink_limiting) {
                /* Vin recovered and no other limiter active */
                msg_clear();
            }
        }

        /* ── Continuity beep + message ─────────────────────────────── */
        if (g_mode == MODE_CONTINUITY && g_vi_enabled) {
            int32_t thr_mV = cnt_to_mv(g_cont_thr)
                             * g_cal.vout_gain / g_cal.vout_div - g_cal.vout_off;
            if (adc.vout_mV < thr_mV) {
                beep_continuous_start();
                msg_post(MSG_WARN, "CONTINUITY: closed", 0u);
            } else {
                beep_continuous_stop();
                msg_clear();
            }
        } else {
            beep_continuous_stop();
            if (g_mode == MODE_CONTINUITY) msg_clear();
        }

        /* ── Display (rate-limited) ─────────────────────────────────── */
        uint64_t now_us = time_us_64();
        if ((now_us - last_display_us) < (uint64_t)DISPLAY_PERIOD_MS * 1000u)
            continue;
        last_display_us = now_us;

        switch (g_mode) {
        case MODE_SUPPLY_SINK: draw_supply_sink_update(adc, mult); break;
        case MODE_SUPPLY:      draw_supply_update(adc, mult);      break;
        case MODE_CONTINUITY:  draw_continuity_update(adc, mult);  break;
        default: break;
        }

        ir_overlay_update();   /* kept for link compat */
        msg_update();          /* handles all overlays including IR */
    }
}

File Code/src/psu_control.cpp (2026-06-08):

#include "psu_control.h"
#include "peripherals.h"
#include "flash_store.h"
#include "display.h"
#include "mcp23s17.h"
#include "pico/stdlib.h"
#include "hardware/gpio.h"

/* ── DAC state ────────────────────────────────────────────────────────── */
int32_t g_dac_cnt[DAC_NUM_CH]  = {0, 0, 0, 0};
bool    g_vi_enabled            = false;
bool    g_isink_enabled         = false;
bool    g_pout_limiting         = false;
bool    g_psink_limiting        = false;

/* ── Channel select ───────────────────────────────────────────────────── */
uint8_t       g_active_ch                  = DAC_VIRT_VSET;
const uint8_t gpb_sel_mask[DAC_NUM_VIRT]   = {(1u<<0),(1u<<2),(1u<<4)};
const uint8_t gpb_sel_vch[DAC_NUM_VIRT]    = {DAC_VIRT_VSET,DAC_VIRT_ISET,DAC_VIRT_ISINK};

/* ── Helpers ──────────────────────────────────────────────────────────── */
static inline uint16_t cnt_to_raw(int32_t cnt)
{
    if (cnt <= 0)           return 0u;
    if (cnt >= DAC_MAX_CNT) return (uint16_t)DAC_MAX_COUNT;
    return (uint16_t)cnt;
}

/* ── Hardware GPIO init ───────────────────────────────────────────────── */
void hw_gpio_init(void)
{
    gpio_init(PIN_SW_HI); gpio_set_dir(PIN_SW_HI, GPIO_OUT); gpio_put(PIN_SW_HI, 1);
    gpio_init(PIN_SW_LO); gpio_set_dir(PIN_SW_LO, GPIO_OUT); gpio_put(PIN_SW_LO, 1);
    gpio_init(PIN_EN_HI); gpio_set_dir(PIN_EN_HI, GPIO_OUT); gpio_put(PIN_EN_HI, 1);
    gpio_init(PIN_EN_LO); gpio_set_dir(PIN_EN_LO, GPIO_OUT); gpio_put(PIN_EN_LO, 1);
}

/* ── DAC update ───────────────────────────────────────────────────────── */
void dac_update(mcp4728 &dac)
{
    bool isink_on = g_isink_enabled && (g_dac_cnt[DAC_CH_A] != 0);
    bool c_on     = g_vi_enabled    && (g_dac_cnt[DAC_CH_C] != 0);
    bool d_on     = g_vi_enabled    && (g_dac_cnt[DAC_CH_D] != 0);

    dac.setPowerDown(isink_on?0:1, isink_on?0:1, c_on?0:1, d_on?0:1);
    dac.analogWriteAll(
        isink_on ? cnt_to_raw(g_dac_cnt[DAC_CH_A]) : 0,
        isink_on ? cnt_to_raw(g_dac_cnt[DAC_CH_A]) : 0,
        c_on     ? cnt_to_raw(g_dac_cnt[DAC_CH_C]) : 0,
        d_on     ? cnt_to_raw(g_dac_cnt[DAC_CH_D]) : 0
    );
    dac.ldacPulse();
    gpio_put(PIN_EN_HI, isink_on ? 0 : 1);
    gpio_put(PIN_EN_LO, isink_on ? 0 : 1);
    mcp23s17_set_pin(MCP_OUT_GPA7, g_vi_enabled);
    mcp23s17_set_pin(MCP_OUT_GPA5, g_isink_enabled);
}

/* ── Power limiting ───────────────────────────────────────────────────── */
void power_limit_update(int32_t vout_mV, int32_t iout_mA, int32_t hii_mA)
{
    /* Power limiting disabled in settings → clear flags and return */
    if (!g_cal.plim_enabled) {
        g_pout_limiting  = false;
        g_psink_limiting = false;
        return;
    }

    int32_t pout_mW   = (vout_mV * iout_mA) / 1000;   /* raw Iout */
    int32_t psink_mW  = (vout_mV * hii_mA)  / 1000;

    /* Vin minimum: if input voltage is too low, ramp down both outputs */
    bool vin_low = (g_cal.vin_min_mV > 0);   /* vin not available here, checked in main */
    (void)vin_low;   /* vin_min applied in main loop via vin_mV */

    bool was_pout  = g_pout_limiting;
    bool was_psink = g_psink_limiting;

    /* Pout limit */
    if (g_cal.pout_max_mW > 0 && pout_mW > g_cal.pout_max_mW
        && g_vi_enabled && g_dac_cnt[DAC_CH_C] > 0) {
        g_dac_cnt[DAC_CH_C]--;
        g_pout_limiting = true;
    } else {
        g_pout_limiting = (g_cal.pout_max_mW > 0 &&
                           pout_mW > (g_cal.pout_max_mW - g_cal.pout_max_mW/10));
    }

    /* Psink limit */
    if (g_cal.psink_max_mW > 0 && psink_mW > g_cal.psink_max_mW
        && g_isink_enabled && g_dac_cnt[DAC_CH_A] > 0) {
        g_dac_cnt[DAC_CH_A]--;
        g_dac_cnt[DAC_CH_B] = g_dac_cnt[DAC_CH_A];
        g_psink_limiting = true;
    } else {
        g_psink_limiting = (g_cal.psink_max_mW > 0 &&
                            psink_mW > (g_cal.psink_max_mW - g_cal.psink_max_mW/10));
    }

    if (!was_pout  && g_pout_limiting)  { beep_special(); msg_post(MSG_WARN, "WARN: Pout limit active",  0u); }
    if (!was_psink && g_psink_limiting) { beep_special(); msg_post(MSG_WARN, "WARN: Psink limit active", 0u); }
    /* Clear warn when both limiters inactive */
    if (!g_pout_limiting && !g_psink_limiting && (was_pout || was_psink))
        msg_clear();
}

/* ── Encoder step multiplier ──────────────────────────────────────────
 * Two modes controlled by g_cal.step_mode:
 *
 * MOMENTARY (step_mode = 0):
 *   GPB3 held → ×10, GPB1 held → ×100, both held → ×1000
 *   Reads GPB level each call (no state).
 *
 * TOGGLE (step_mode = 1):
 *   GPB3 falling edge cycles ×1 → ×10 → ×100 → ×1
 *   GPB1 falling edge resets to ×1
 *   g_step_mult holds persistent state.
 */
static int32_t g_step_mult    = 1;
static bool    g_buttons_primed = false;
static bool    g_step_primed    = false;

static void step_mult_update(uint8_t gpb)
{
    if (g_cal.step_mode == 0) {
        /* Momentary: level-based, no state needed */
        int32_t m = 1;
        if ((gpb & (1u<<3)) == 0) m *= 10;
        if ((gpb & (1u<<1)) == 0) m *= 100;
        g_step_mult = m;
        return;
    }

    /* Toggle: falling-edge based */
    static uint8_t gpb_prev = 0xFFu;
    if (!g_step_primed) { gpb_prev = gpb; g_step_primed = true; return; }

    uint8_t fell = (uint8_t)(gpb_prev & ~gpb);
    if (fell & (1u<<3)) {   /* GPB3: cycle 1→10→100→1 */
        if      (g_step_mult == 1)   g_step_mult = 10;
        else if (g_step_mult == 10)  g_step_mult = 100;
        else                         g_step_mult = 1;
    }
    if (fell & (1u<<1))     /* GPB1: reset to ×1 */
        g_step_mult = 1;
    gpb_prev = gpb;
}

int32_t encoder_step_multiplier(uint8_t gpb)
{
    step_mult_update(gpb);
    return g_step_mult;
}

void apply_encoder_main(int32_t multiplier)
{
    int32_t delta = enc_consume();
    if (delta == 0) return;
    int32_t step = (int32_t)ENC_STEP * multiplier;
    if (g_active_ch == DAC_VIRT_ISINK) {
        int32_t cnt = g_dac_cnt[DAC_CH_A] + delta * step;
        if (cnt < DAC_MIN_CNT) cnt = DAC_MIN_CNT;
        if (cnt > DAC_MAX_CNT) cnt = DAC_MAX_CNT;
        g_dac_cnt[DAC_CH_A] = g_dac_cnt[DAC_CH_B] = cnt;
    } else {
        int32_t cnt = g_dac_cnt[g_active_ch] + delta * step;
        if (cnt < DAC_MIN_CNT) cnt = DAC_MIN_CNT;
        if (cnt > DAC_MAX_CNT) cnt = DAC_MAX_CNT;
        g_dac_cnt[g_active_ch] = cnt;
    }
}

/* ── Button handling ──────────────────────────────────────────────────── */

void process_buttons_main_reset(void)
{
    g_buttons_primed = false;
    g_step_primed    = false;
}
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

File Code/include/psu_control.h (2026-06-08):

#pragma once
#include "psu_types.h"
#include "mcp4728.h"
#include <stdint.h>
#include <stdbool.h>

#define PIN_SW_HI    13
#define PIN_SW_LO    12
#define PIN_EN_HI    20
#define PIN_EN_LO    21

/* ── Virtual channel select tables ───────────────────────────────────── */
extern uint8_t       g_active_ch;
extern const uint8_t gpb_sel_mask[DAC_NUM_VIRT];
extern const uint8_t gpb_sel_vch[DAC_NUM_VIRT];

/* ── DAC setpoints ────────────────────────────────────────────────────── */
extern int32_t g_dac_cnt[DAC_NUM_CH];   /* main supply + sink setpoints   */

/* ── Output enables ───────────────────────────────────────────────────── */
extern bool g_vi_enabled;
extern bool g_isink_enabled;

/* ── Power limiting state ─────────────────────────────────────────────── */
extern bool g_pout_limiting;
extern bool g_psink_limiting;

/* ── Init & periodic ─────────────────────────────────────────────────── */
void hw_gpio_init(void);
void dac_update(mcp4728 &dac);
void power_limit_update(int32_t vout_mV, int32_t iout_mA, int32_t hii_mA);
void apply_encoder_main(int32_t multiplier);

/* Returns true if cal menu requested (GPB5), puts mode-cycle in gpb7_fell */
bool process_buttons_main(uint8_t gpa, uint8_t gpb, bool *gpb7_fell_out);
void process_buttons_main_reset(void);

int32_t encoder_step_multiplier(uint8_t gpb);

/* Utility: convert DAC counts to millivolts */
static inline int32_t cnt_to_mv(int32_t cnt)
{
    return (int32_t)((int64_t)cnt * DAC_VREF_MV / DAC_MAX_COUNT);
}

/* Compute setpoint display value via calibration */
static inline int32_t setpt_disp(int32_t cnt, int32_t gain, int32_t div, int32_t off)
{
    return cnt_to_mv(cnt) * gain / div - off;
}

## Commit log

2025-09-11 added buck power supplies
    [LabSupply 2025-2026.kicad_sch]
2025-10-03 almost complete schematics
    [LabSupply 2025-2026.kicad_sch]
2025-11-06 upload power board V0.1
    [LabSupply 2025-2026.kicad_pcb, LabSupply 2025-2026.kicad_sch, bom.csv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]
2026-05-11 initial upload
    3d files not yet finished.
    some errors in schematics
    [100W 24V power supply.SLDPRT, 60mm fan.SLDPRT, BackPanel1.SLDPRT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]
2026-05-16 bigger clearance on 2,2mm screws
    [front panel mount rear^supply_assem.STL]
2026-05-17 added chamfer
    [front panel cover^supply_assem.STL]
2026-05-17 upload
    needs to fit perfectly on cherrym MX buttons
    [button handle v2.STL]
2026-05-18 newer FW
    Fan control, beeper, menu + saving to flash, IR receiver, power calculation
2026-05-18 upload
    assembly almost finished.
    Added cheery MX buttons with text for multicolor 3D print
    [BackPanel1.DXF, BottomPanel1.DXF, C1~C0603~C0603_L1.6-W0.8-H0.8~fHK2.SLDASM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]
2026-05-18 upload buttons with bigger font
    [button handle tapered hole V1 AMS.STL, button handle tapered hole V2 AMS.SLDPRT, button handle tapered hole V2 AMS.STL]
2026-05-19 bigger font
    [button handle tapered hole V2 NO_AMS.SLDPRT, button handle tapered hole V2 NO_AMS.STL]
2026-05-19 Update button handle tapered hole V2 AMS.STL
    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
    [button handle tapered hole V2 AMS.STL]
2026-05-20 Update button handle tapered hole V2 AMS.STL
    0,1mm bigger text
    [button handle tapered hole V2 AMS.STL]
2026-06-08 moved files around
    [LabSupply 2025-2026.csv, LabSupply 2025-2026.kicad_sch, LabSupply_2025-2026_control.kicad_pcb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]
2026-06-08 update
    now error mesaage shows on screen instead of only beeping.
    IR decoding now works with NEC protocol.
    [display.cpp, flash_store.cpp, main.cpp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]
2026-06-08 Revise firmware flashing instructions
    Updated steps for flashing firmware on Raspberry Pi.
